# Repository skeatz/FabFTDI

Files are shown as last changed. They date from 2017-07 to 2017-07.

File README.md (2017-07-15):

# FabFTDI Projects
This repository contains all my FabFTDI projects:
FabFTDI projects which make use of avr microcontrollers are based on the V-USB library from [obdev](https://www.obdev.at/products/vusb/index.html) and the AVR-CDC work done by [K Ishikawa](http://www.recursion.jp/prose/avrcdc/) at recursion.jp.

A few points about the AVR-CDC protocol with Atmel microcontrollers - AVR-CDC enables a PC to communicate with a low-speed USB device (AVR microcontroller) through a virtual COM port.

The table below (from **recursion.jp**) lists the specifications for AVR-CDC with different AVR microcontrollers:
* AVR-CDC with USART (ATmega8/48/88/168/328)
    * speed: 600 - 38400 bps
    * datasize: 5 - 8 bits
    * parity: none/even/odd
    * stopbit: 1/2
    * controls: DTR, RTS, CTS
* AVR-CDC with USART (ATtiny2313)
    * speed: 600 - 38400 bps
    * datasize: 8
    * parity: none
    * stopbit: 1
* AVR-CDC without USART (ATtiny45/85)
    * speed: 1200 - 4800 bps
    * datasize: 8
    * stopbit: 1...

1. **[CH340G-based FabFTDI](fabftdi-ch340g.md)**
   * speeds up to 2 Mbps (loopback)
   * tested up to 250 kbps with ESP8266 module
   * uses hardware USB-to-TTL chip
   * low cost (USD0.40 per IC for 10 pcs)
2. **[ATmega8-based FabFTDI](fabftdi-mega8.md)**
   * speeds up to 2 Mbps (loopback)
   * tested up to 250 kbps with ESP8266 module
   * hardware UART
   * uses V-USB/AVR-CDC library
3. **[ATtiny2313-based FabFTDI](fabftdi-tiny2313.md)**
   * speed up to 57600 bps
   * hardware UART
   * uses V-USB library
4. **[ATtiny45-based FabFTDI (w/crystal)](fabftdi-tiny45x.md)**
   * speeds up to 4800 bps
   * uses V-USB library
5. **[ATtiny45-based FabFTDI (w/internal PLL)](fabftdi-tiny45.md)**
   * speeds up to 4800 bps
   * uses V-USB library

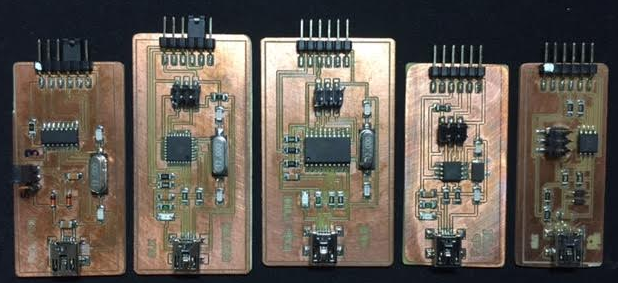
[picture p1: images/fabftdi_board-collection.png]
Fab FTDI collection


Collection of FabFTDI boards (from left): CH340g-based, ATmega8-based, ATtiny2313-based, ATtiny45-based w/crystal, ATtiny45-based w/internal oscillator

*Copyright (c) Steven Chew*...

*MIT license*

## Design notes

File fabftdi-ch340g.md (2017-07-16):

## Fab FTDI (CH340g)
* CH340g-based Fab FTDI
* tested up to:
  * 2 Mbps on loopback
  * 250000 bps with esp8266
* RTS/CTS flow control

## Schematic & Board Layout
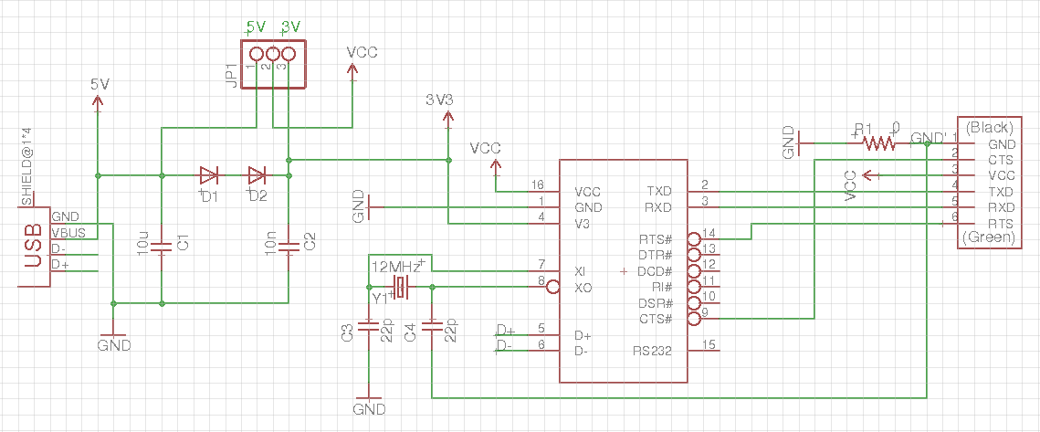
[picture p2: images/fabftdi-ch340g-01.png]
FabFTDI-CH340g Schematic


JP1 allows selection of 5V or 3.6V supply for FTDI interface

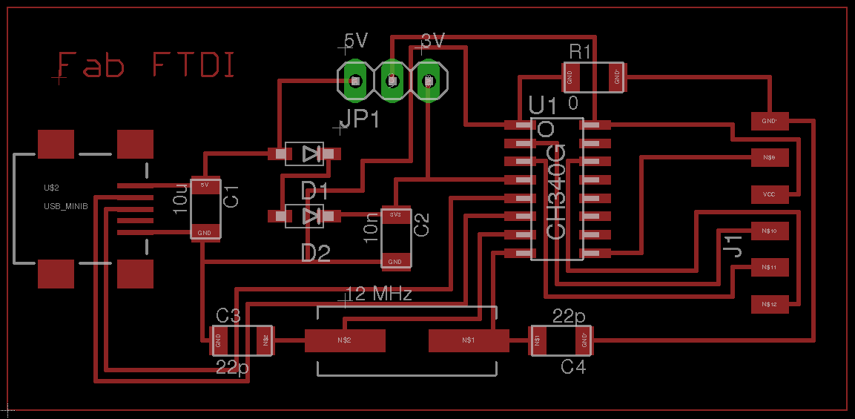
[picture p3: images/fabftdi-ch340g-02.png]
FabFTDI-CH340g layout


Mill and stuff the PCB.

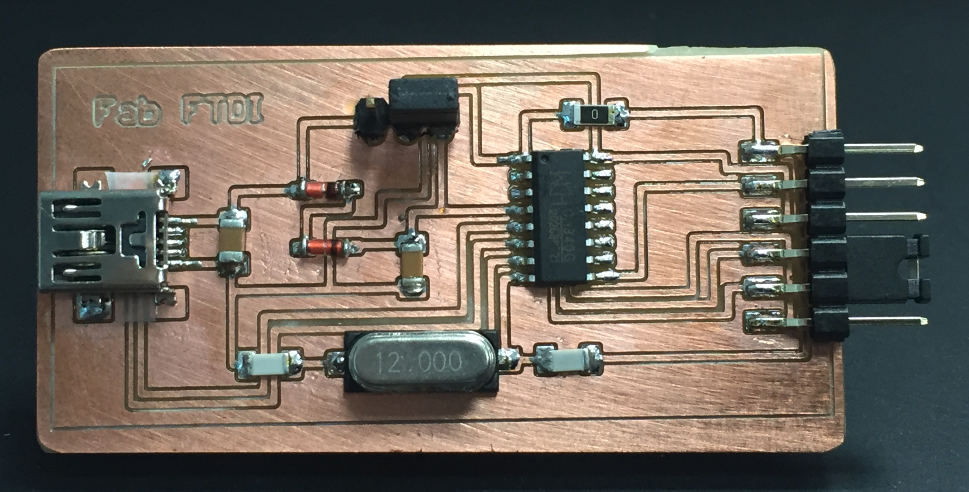
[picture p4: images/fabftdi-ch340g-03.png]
PCB after stuffing


Fab Modules downloads (1269dpi):

* [Fab modules - Board Outline](images/fabftdi-ch340g_outline.png)
* [Fab modules - Board traces](images/fabftdi-ch340g_traces.png)

## Component List
| Component | Component |
| :--- | :--- |
| 1 x CH340G | 1 x Mini-USB |
| 1 x 10uF  capacitor | 1 x PinHD 1x3|
| 1 x 10nF capacitor  | 1 x PinHD 1x6|
| 2 x 22pF capacitor  | 2 x Diodes 1N4148 |
| 1 x 12MHz crystal | 1 x 0 ohm R  |

## Testing the Board
Plug the FabFTDI-CH340g board into your computer's USB port. On a Windows machine, look for the COMport under Control Panel > System > Device Manager. You may need to install the CH340g driver. A signed driver can be downloaded here --> [CH340g driver](http://www.arduined.eu/files/CH341SER.zip). If you need help in installing the CH340g driver, you can refer to this [article](http://www.arduined.eu/ch340g-converter-windows-7-driver-download/).

Linux PCs and MacBooks should be able to detect the FabFTDI board without any driver. To check the device port:

`lsusb`

should display *QinHeng Electronics HL-340 USB-Serial adapter*

`ls /dev/ttyU*`

should display the device port.

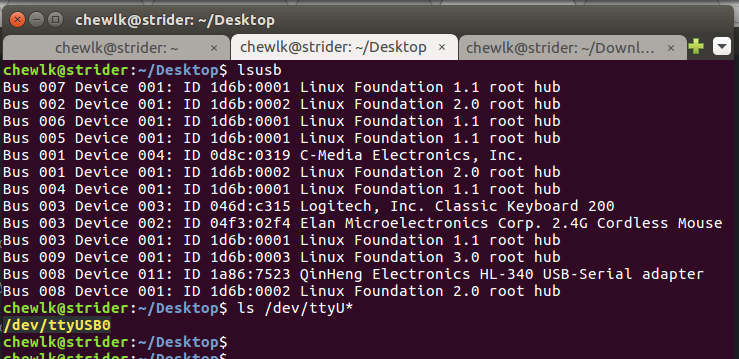
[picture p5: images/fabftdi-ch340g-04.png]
Detecting FabFTDI device port


To perform loopback test on the board, jumper the TXD and RXD pins. Open your favorite terminal emulation software, e.g. Arduino IDE or picocom. Select the device port.

E.g. for Arduino IDE on Linux, select Tools > Port > /dev/ttyUSB0. Click Serial Monitor (**Ctrl+Shift+M**). Select *Both NL & CR*. Select the desired baud rate. Type a message on the transmit window and press **Enter** or click the **Send** button. You should see the message appearing on the received data window.

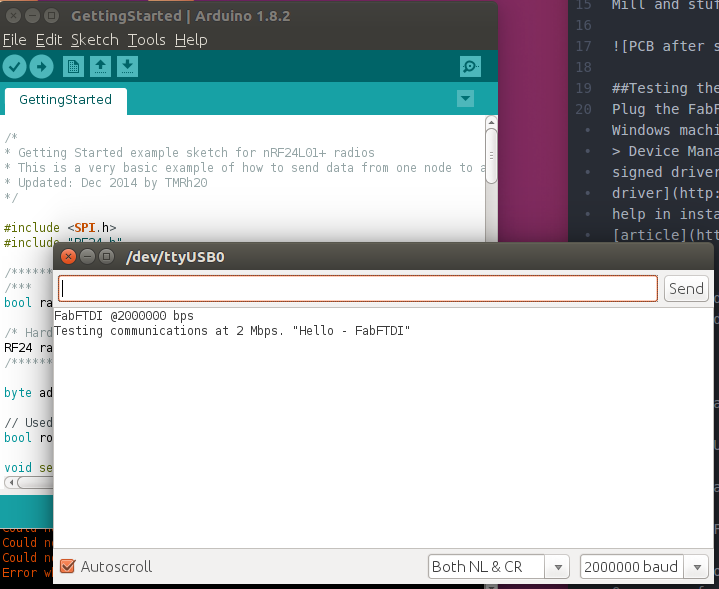
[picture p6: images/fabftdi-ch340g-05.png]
Loopback test


As stated at the start of this tutorial, I have tested the board up to 2 Mbps on loopback and 115200 bps on an ESP8266 module.

Good luck and have fun with your FabFTDI board!

## Files
* [Eagle Schematic](files/ch340g/fabftdi-ch340g.sch)

* [Eagle PCB layout](files/ch340g/fabftdi-ch340g.brd)

*Copyright (c) 2017-Steven Chew*

*MIT license*

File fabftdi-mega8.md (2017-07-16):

## FabFTDI - ATmega8
* ATmega8A-AU based Fab FTDI
* tested up to:
  * 2 Mbps on loopback
  * 250000 bps with ESP8266
* uses V-USB library
  * AVR-CDC from [Recursion.jp](http://www.recursion.jp/prose/avrcdc/)

## Schematic & Board Layout
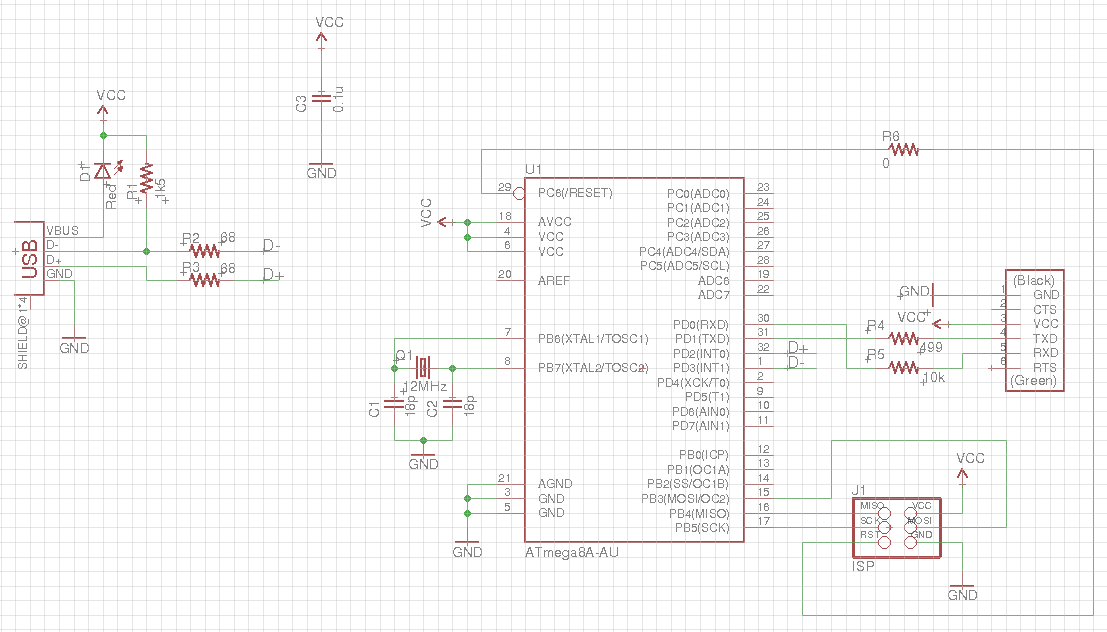
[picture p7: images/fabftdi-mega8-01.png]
FabFTDI-mega8 schematic


I opted to use a 12 MHz crystal in my design because I had some handy (bought for my CH340g-based FabFTDI). Also, ***the compiled .hex file is for an ATmega8 with 12 MHz crystal***. If you are using a different crystal oscillator, you will need to recompile from [source](http://www.recursion.jp/prose/avrcdc/download.html).

Only the TXD and RXD pins are implemented on the FTDI interface (no RTS/CTS).

The FTDI-Vcc is 3.6V. This means that it can work directly with 3.3V-based systems like the ESP8266. If you are interfacing with 5V boards, **do not connect the FTDI-Vcc to the target Vcc**, as I have not implemented 3.6V zeners for the USB D+ and D- lines.

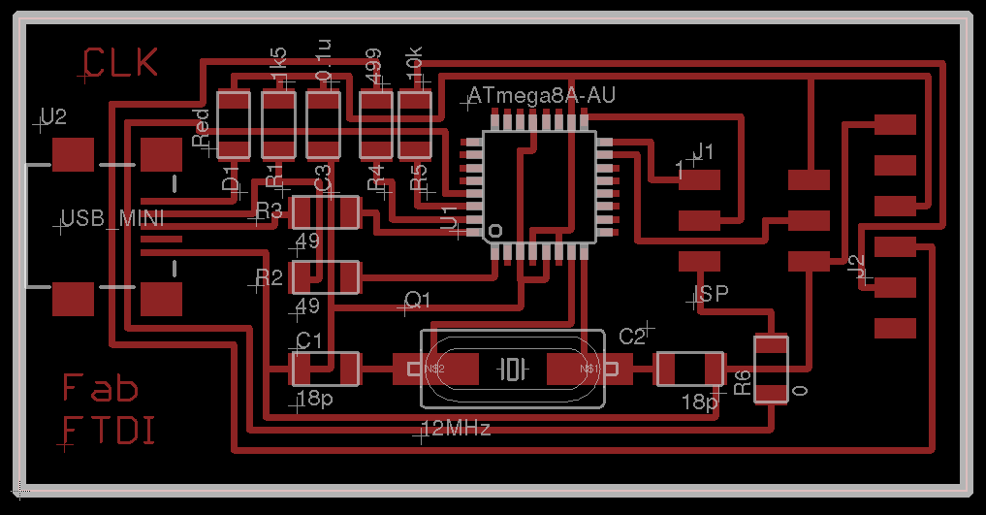
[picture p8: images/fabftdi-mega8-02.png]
FabFTDI-mega8 board layout


Fab modules downloads (1269dpi):
* [Fab modules - Board outline](images/fabftdi-mega8_outline.png)
* [Fab modules - Board traces](images/fabftdi-mega8_traces.png)

Mill and stuff the PCB.

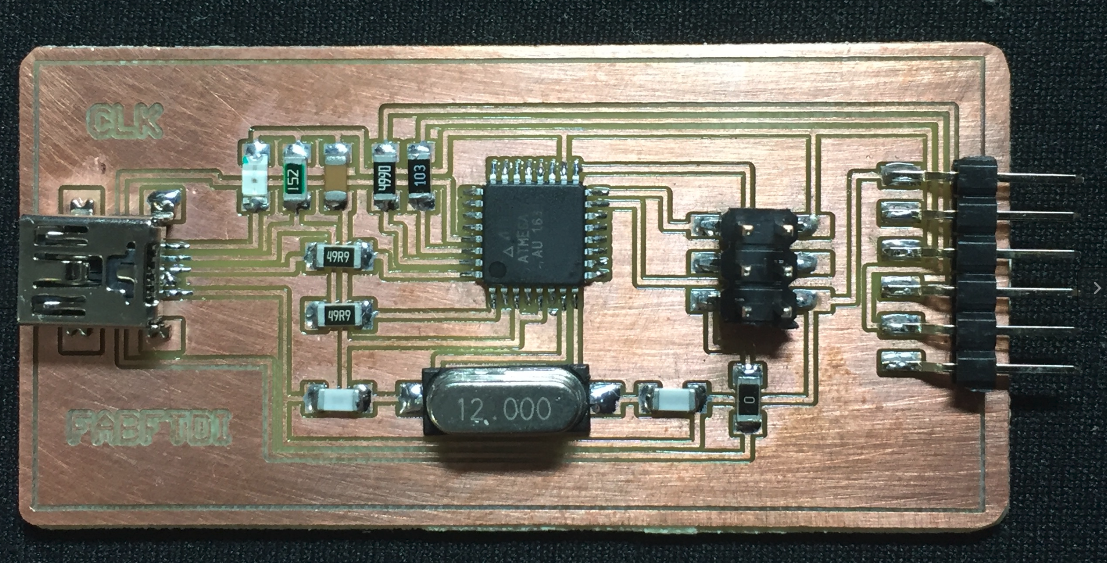
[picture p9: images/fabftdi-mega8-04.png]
FabFTDI board after stuffing


## Component List
| Components | Components |
| :--- | :--- |
| 1 x ATmega8A-AU | 1 x Mini-USB |
| 1 x 12 MHz Crystal | 1 x PinHD 2x3 ISP |
| 1 x LED red | 1 x PinHD 1x6 FTDI |
| 2 x 18pF capacitor | 1 x 0.1uF capacitor |
| 2 x 49 ohm R | 1 x 1k5 ohm R |
| 1 x 499 ohm R | 1 x 10k ohm R |
| 1 x 0 ohm R |

## Programming the Fab FTDI board
Unlike the CH340g-based FabFTDI, the ATmega8-based FabFTDI board uses the V-USB software library to implement USB-to-TTL conversion, i.e. it has to be programmed with the correct firmware before it can be used.

You need both an ISP programmer like the [FabISP](http://docs.academany.org/FabAcademy-Tutorials/_book/en/week4_electronic_production/fabisp.html) and [avrdude](http://savannah.nongnu.org/projects/avrdude) to program the FabFTDI-mega8 board. Instructions for installing avrdude can be found in the Fab Academy [tutorials](http://docs.academany.org/FabAcademy-Tutorials/_book/en/week4_electronic_production/fabisp.html) page. If you are using a different speed crystal oscillator, you will need to re-compile the firmware from [source](http://www.recursion.jp/prose/avrcdc/download.html).

Download the [FabFTDI-mega8 firmware](files/mega8/cdcmega8.hex).

Flash the firmware onto the FabFTDI-mega8 board using avrdude:

`avrdude -c usbtiny -p m8 -U flash:w:cdcmega8.hex -U lfuse:w:0xff:m -U hfuse:w:0x8f:m`

If you have managed to successfully flash the firmware onto the FabFTDI-mega8 board, give yourself a **pat** on the back. You are almost home.

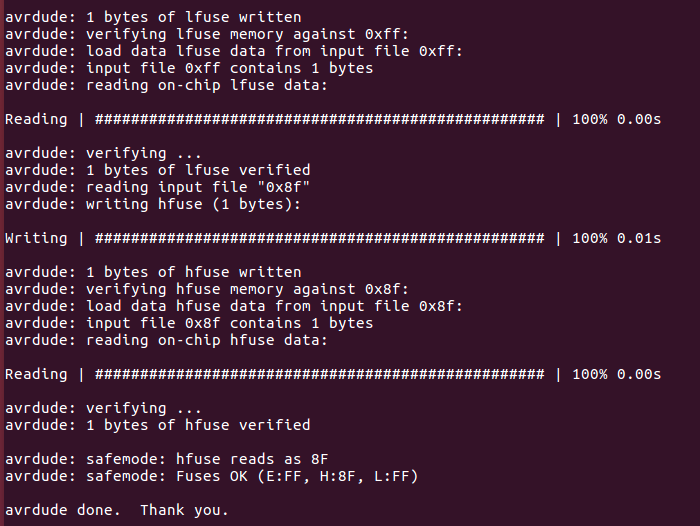
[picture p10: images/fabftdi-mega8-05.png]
Flashing the firmware


## Testing the Board
Plug the FabFTDI-mega8 board into your computer's USB port. Your computer should recognise the FabFTDI-mega8 board directly, as it implements the HIDinterface protocol.

On Windows machines, look for the COMport under Control Panel > System > Device Manager. On Linux or OSX machines, type the commands:
```
lsusb
ls /dev/ttyACM*
```
The FabFTDI-mega8 should appear as ***ID 16c0:05e1 Van Ooijen Technische Informatica Free shared USB VID/PID pair for CDC devices*** and ***/dev/ttyACM0***

To perform loopback test on the FabFTDI-mega8 board, jumper the TXD and RXD pins. Open your favorite terminal emulation software, e.g. Arduino IDE or picocom. Select the device port.

E.g. for Arduino IDE on Linux, select Tools > Port > /dev/ttyACM0. Click Serail Monitor (**Ctrl+Shift+M**). Select *Both NL & CR*. Select the desired baud rate. Type a message on the transmit window and press **Enter** or click the **Send** button. You should see the message appearing ont the received data window.

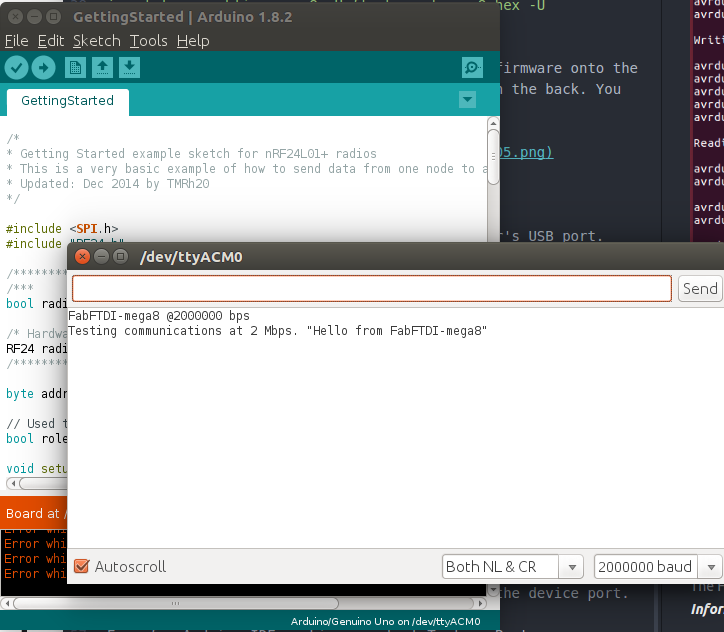
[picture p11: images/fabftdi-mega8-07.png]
Loopback test


As stated at the start of this tutorial, I have tested the FabFTDI-mega8 board up to 2 Mbps on loopback and 250 kbps on an ESP8266 module.

You can substitute the ATmega8A-AU with the ATmega328p-AU as the 2 devices are pin compatible.

Good luck and have fun with your FabFTDI board!

## Files
* [Eagle Schematic](files/mega8/fabftdi-mega8.sch)

* [Eagle PCB layout](files/mega8/fabftdi-mega8.brd)

* [FabFTDI-mega8 firmware (12MHz crystal)](files/mega8/cdcmega8.hex)

* [Firmware for ATmega328p (12MHz crystal)](files/mega8/cdcmega328p.hex)

*Copyright (c) 2017 Steven Chew*...

*MIT license*

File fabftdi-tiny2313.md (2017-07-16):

## FabFTDI - ATtiny2313
* ATtiny2313-based Fab FTDI
* hardware UART
* tested up to:
  * 57600 bps on loopback
* uses v-USB library
  * AVR-CDC from [Recursion.jp](http://www.recursion.jp/prose/avrcdc/)

## Schematic & Board Layout
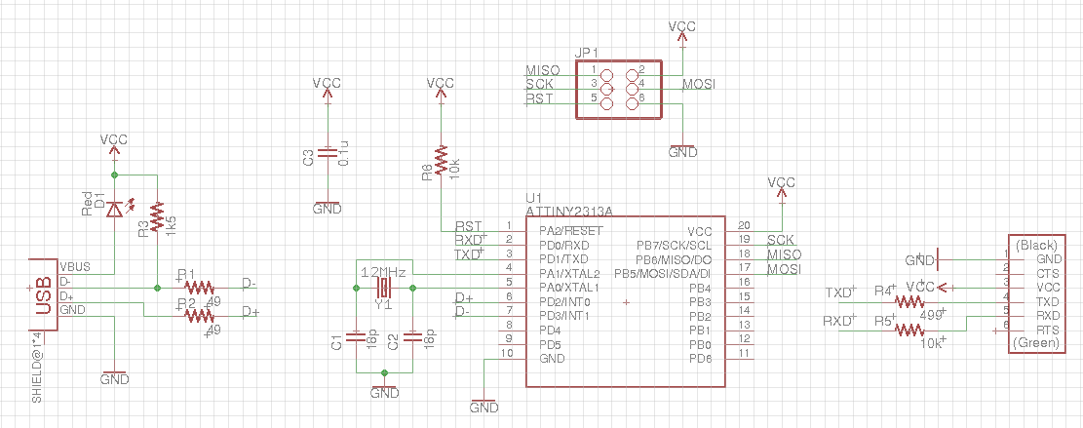
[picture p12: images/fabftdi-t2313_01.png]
Eagle schematic


I opted to use a 12 MHz crystal in my design because I had some handy (bought for my CH340g-based FabFTDI). Also, the ***compiled .hex file is for an ATtiny2313 with 12 MHz crystal.***. If you are using a different crystal oscillator, you will need to recompile the program from [source](http://www.recursion.jp/prose/avrcdc/download.html).

The FTDI Vcc is 3.6V, obtained by dropping the USB 5V through an LED. This means that it can work directly with 3.3V-based systems like the ESP8266 or ATxmega16E5. If you are interfacing with 5V boards, **do not connect the FTDI Vcc to the target Vcc**, as I have not implemented 3.6V zeners for the USB D+ and D= lines.

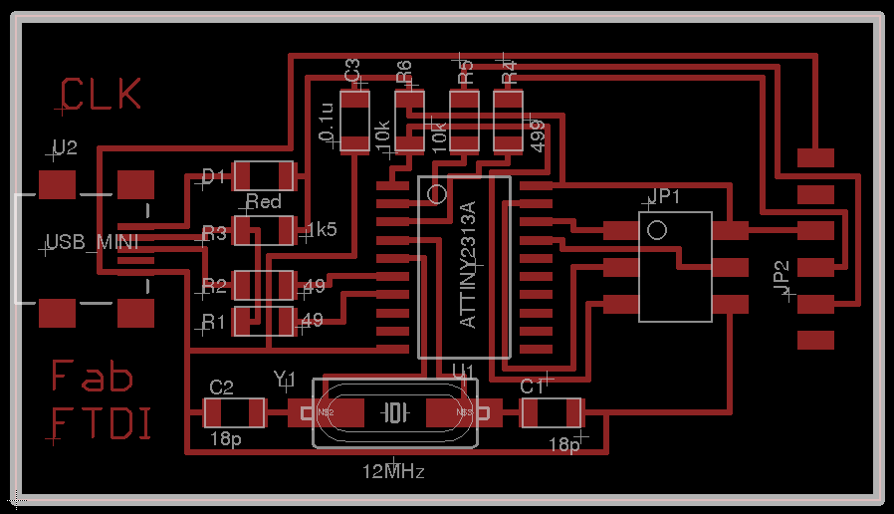
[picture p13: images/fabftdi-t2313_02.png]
Eagle PCB layout


*FabFTDI-t2313 pcb layout*

Fab modules downloads (1269dpi):

* [Fab modules - board outline](images/fabftdi-t2313_outline.png)
* [Fab modules - board traces](images/fabftdi-t2313_traces.png)

Mill and stuff the PCB

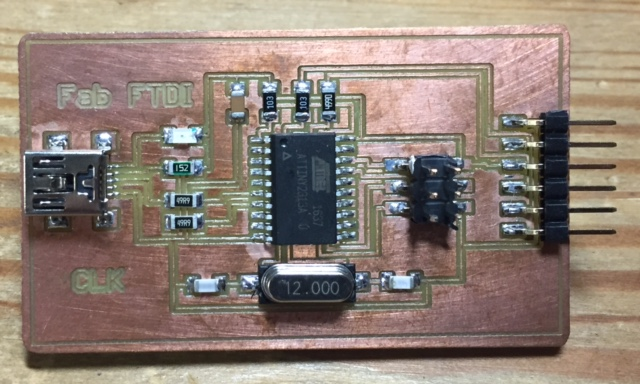
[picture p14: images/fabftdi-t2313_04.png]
FabFTDI board after stuffing


## Component List
| Component | Component |
| :--- | :--- |
| 1 x ATtiny2313 | 1 x Mini-USB |
| 1 x 12 MHz crystal | 1 x PinHD 2x3 ISP |
| 1 x LED red | 1 x PinHD 1x6 FTDI |
| 2 x 18pF capacitor | 1 x 0.1uF capacitor |
| 2 x 10k ohm R | 1 x 1k5 ohm R |
| 1 x 499 ohm R | 2 x 49 ohm R |

## Programming the Fab FTDI board
Unlike the CH340g-based FabFTDI, the ATmega8-based FabFTDI board uses the V-USB software library to implement USB-to-TTL conversion, i.e. it has to be programmed with the correct firmware before it can be used.

You need both an ISP programmer like the [FabISP](http://docs.academany.org/FabAcademy-Tutorials/_book/en/week4_electronic_production/fabisp.html) and [avrdude](http://savannah.nongnu.org/projects/avrdude) to program the FabFTDI-mega8 board. Instructions for installing avrdude can be found in the Fab Academy [tutorials](http://docs.academany.org/FabAcademy-Tutorials/_book/en/week4_electronic_production/fabisp.html) page. If you are using a different speed crystal oscillator, you will need to re-compile the firmware from [source](http://www.recursion.jp/prose/avrcdc/download.html).

Download the [FabFTDI-t2313 firmware](files/tiny2313/cdc2313.hex).

Flash the firmware onto the FabFTDI-t2313 board using avrdude:

`avrdude -c usbtiny -p t2313 -U flash:w:cdc2313.hex -U lfuse:w:0xff:m -U hfuse:w:0xcd:m`

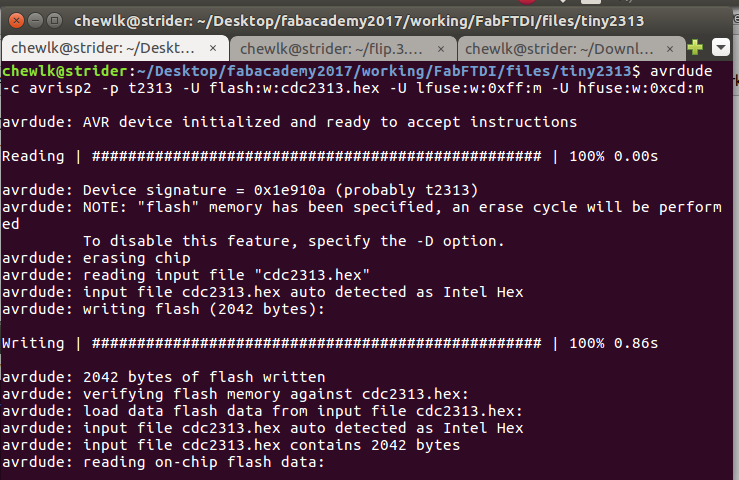
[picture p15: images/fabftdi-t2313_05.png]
Flashing the firmware


If you have managed to successfully flash the firmware onto the FabFTDI-t2313 board, give yourself a **pat** on the back. You are almost home.

## Testing the Board
Plug the FabFTDI-t2313 board into your computer's USB port. Your computer should recognise the FabFTDI-t2313 board directly, as it implements the HIDinterface protocol.

On Windows machines, look for the COMport under Control Panel > System > Device Manager. On Linux or OSX machines, type the commands:
```
lsusb
ls /dev/ttyACM*
```
The FabFTDI-t2313 should appear as ***ID 16c0:05e1 Van Ooijen Technische Informatica Free shared USB VID/PID pair for CDC devices*** and ***/dev/ttyACM0***

To perform loopback test on the FabFTDI-mega8 board, jumper the TXD and RXD pins. Open your favorite terminal emulation software, e.g. Arduino IDE or picocom. Select the device port.

E.g. for Arduino IDE on Linux, select Tools > Port > /dev/ttyACM0. Click Serail Monitor (**Ctrl+Shift+M**). Select *Both NL & CR*. Select the desired baud rate. Type a message on the transmit window and press **Enter** or click the **Send** button. You should see the message appearing ont the received data window.

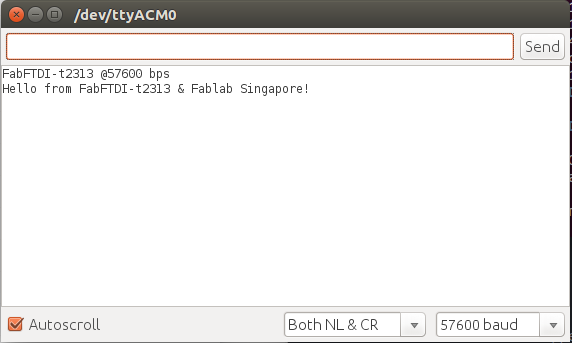
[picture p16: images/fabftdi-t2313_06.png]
Loopback test


As stated at the start of this tutorial, I have tested the FabFTDI-t2313 board up to 57600 bps on loopback only.

Good luck and have fun with your FabFTDI board!

## Files
* [Eagle Schematic](files/tiny2313/fabftdi-tiny2313.sch)

* [Eagle PCB layout](files/tiny2313/fabftdi-tiny2313.brd)

* [FabFTDI-t2313 firmware (12MHz crystal)](files/tiny2313/cdc2313.hex)

* [FabFTDI-t2313 firmware (16MHz crystal)](files/tiny2313/cdc2313-16.hex)

* [FabFTDI-t2313 firmware (20MHz crystal)](files/tiny2313/cdc2313-20.hex)

*Copyright (c) 2017 Steven Chew*...

*MIT license*

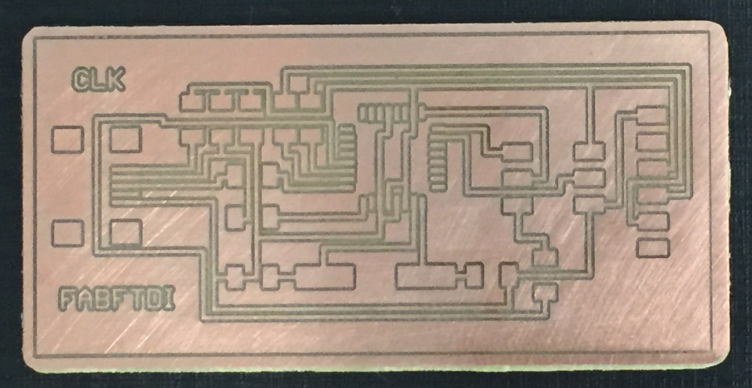
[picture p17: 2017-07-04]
images/fabftdi-mega8-03.png

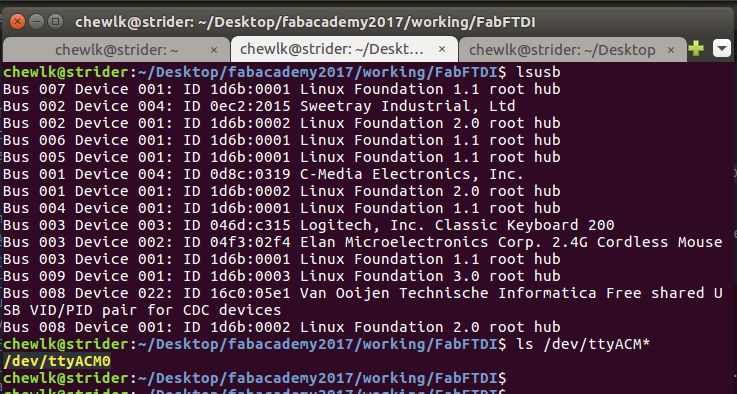
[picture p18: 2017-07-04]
images/fabftdi-mega8-06.png

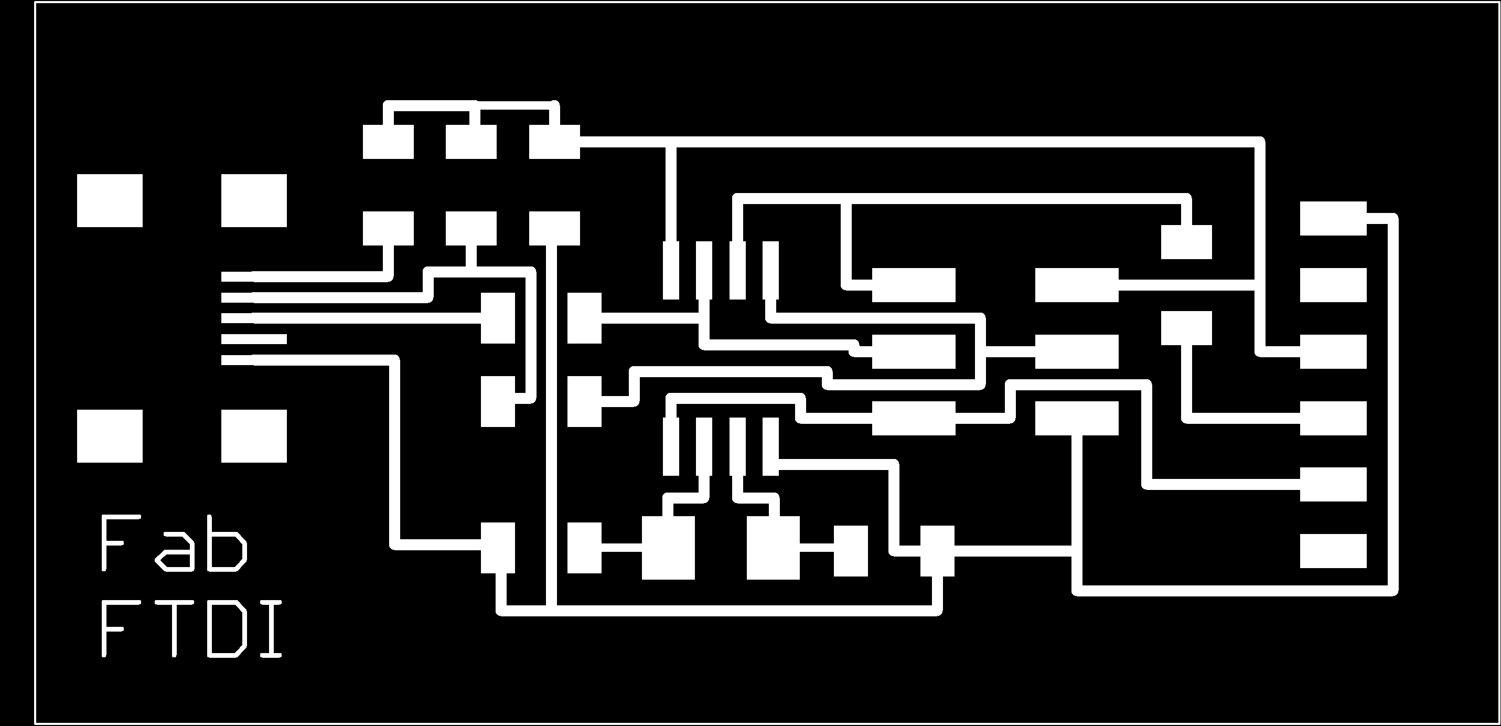
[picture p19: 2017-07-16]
images/fabftdi-t45x_02.png

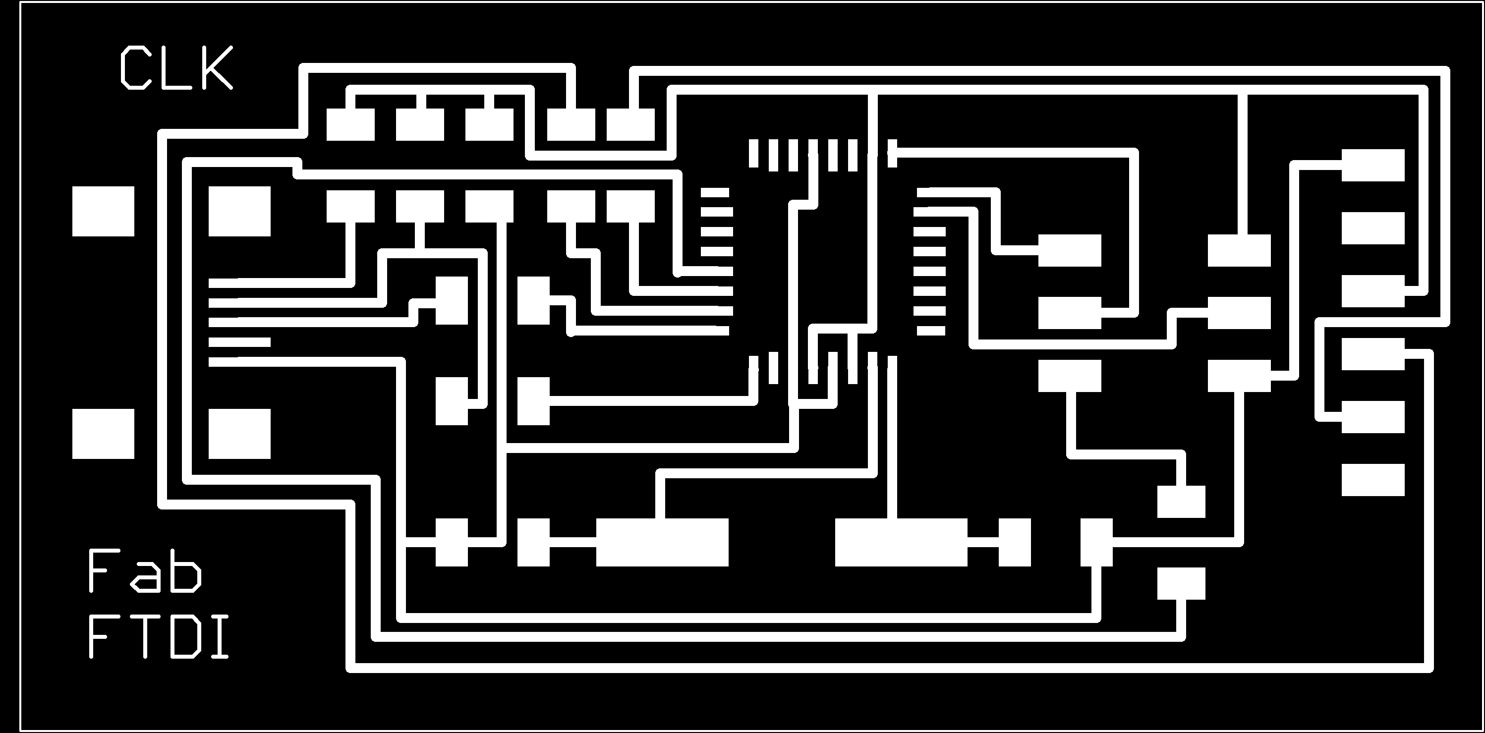
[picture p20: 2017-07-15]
images/fabftdi-mega8_traces.png

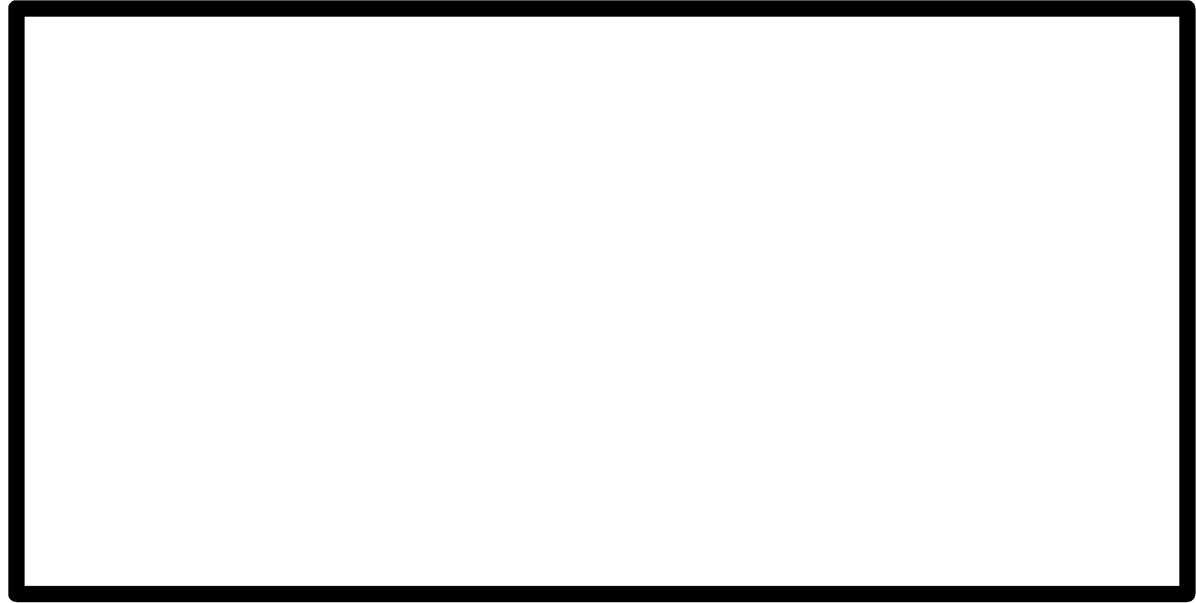
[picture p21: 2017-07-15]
images/fabftdi-mega8_outline.png

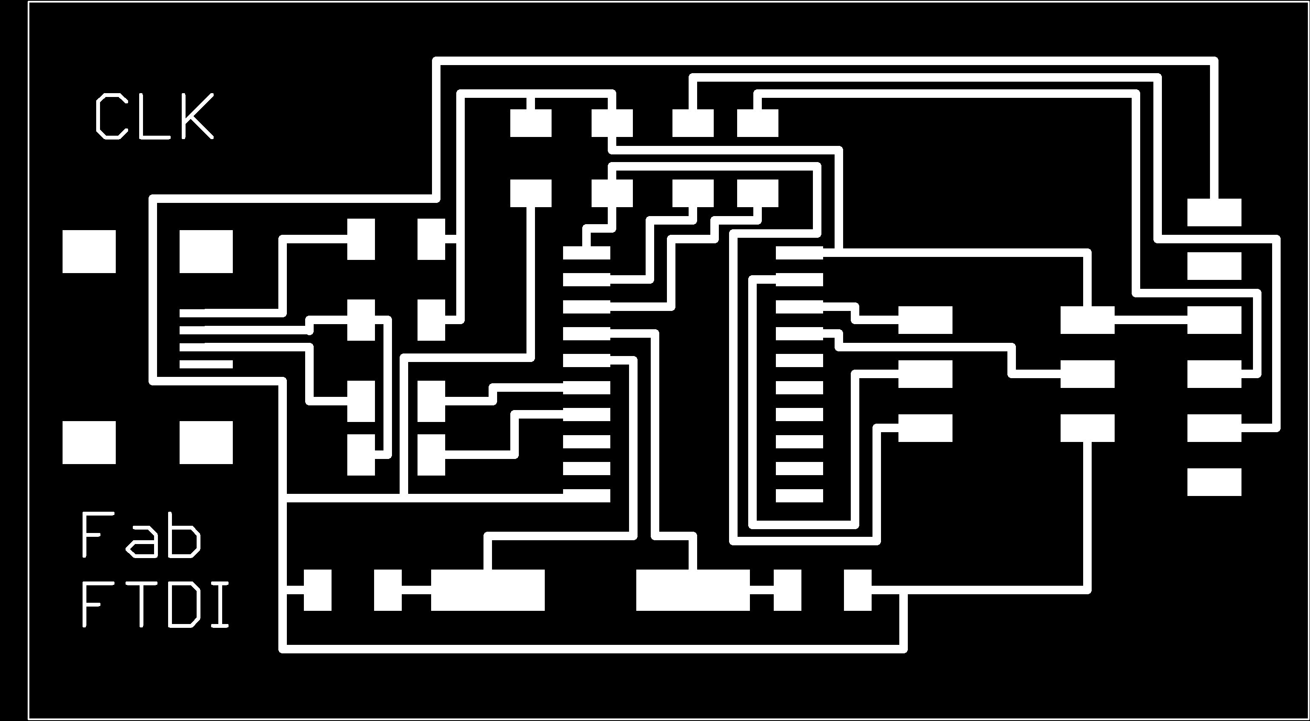
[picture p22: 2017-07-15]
images/fabftdi-t2313_traces.png

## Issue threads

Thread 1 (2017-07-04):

add fab-production files

Madouc, 2017-07-04:
Cool! thanks for these.
to increase adaptation i would add board, outline and component png´s that are ready for production to the repository.

skeatz, 2017-07-05:
Yup; will do so later. I've been working on these for the past couple of weeks, when I could spare the time. Only just started writing up the tutorials. Will improve upon it as I go along.

skeatz, 2017-07-05:
Hi Bas,

Noted. Will update documents to include these later. Was working on these boards during the past 2 weeks, when I had the time. Decided to do a quick write-up & post to GitHub late last night, so kind of a rush job.

cheers,

Steven

________________________________
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

skeatz, 2017-07-15:
Added traces & outline pngs for fab modules. Board layout & finished board already included.

Closed 2017-07-15.

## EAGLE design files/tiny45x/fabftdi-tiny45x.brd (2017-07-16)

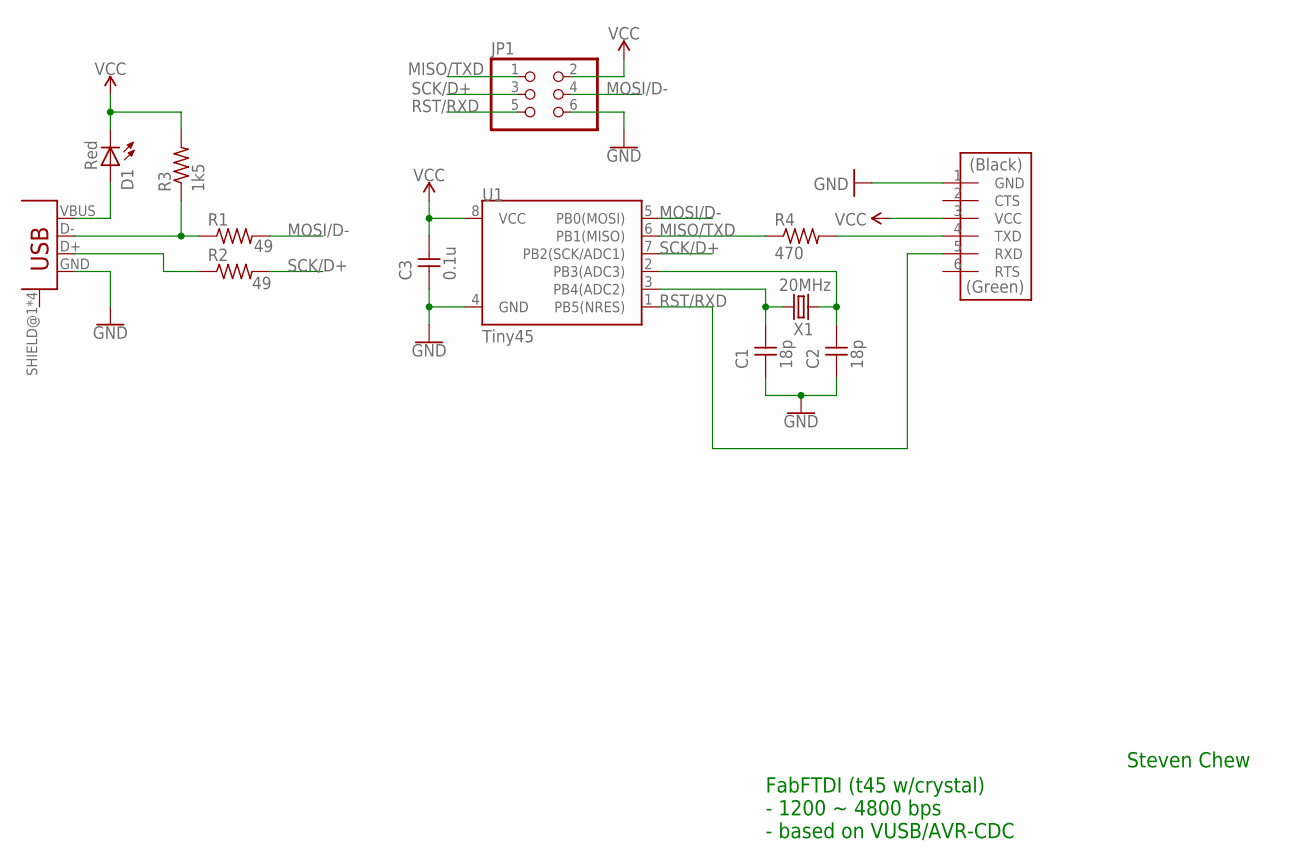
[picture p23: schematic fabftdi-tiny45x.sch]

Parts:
C1, C2: 18p; C1206FAB
C3: 0.1u; C1206FAB
D1: Red; LED1206FAB
JP1: PINHD-2X3-SMDFAB; 2X03SMD-FAB
JP2: FTDI-SMD-HEADER; 1X06SMD
R1, R2: 49; R1206FAB
R3: 1k5; R1206FAB
R4: 470; R1206FAB
U1: Tiny45; SO08-EIAJ
U2: USB_MINI
X1: 20MHz; 2-SMD-5X3MM

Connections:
GND: C1.1, C2.1, C3.1, JP1.6, JP2.1 (GND), U1.4 (GND), U2.GND
MISO/TXD: JP1.1, R4.1, U1.6 (PB1(MISO))
MOSI/D-: JP1.4, R1.2, U1.5 (PB0(MOSI))
unnamed: R1.1, R3.1, U2.D-
unnamed: R2.1, U2.D+
unnamed: D1.1 (A), U2.VBUS
unnamed: C1.2, U1.3 (PB4(ADC2)), X1.P$2 (2)
unnamed: C2.2, U1.2 (PB3(ADC3)), X1.P$1 (1)
unnamed: JP2.4 (TXD), R4.2
RST/RXD: JP1.5, JP2.5 (RXD), U1.1 (PB5(NRES))
SCK/D+: JP1.3, R2.2, U1.7 (PB2(SCK/ADC1))
VCC: C3.2, D1.2 (C), JP1.2, JP2.3 (VCC), R3.2, U1.8 (VCC)

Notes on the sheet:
Steven Chew
FabFTDI (t45 w/crystal) - 1200 ~ 4800 bps - based on VUSB/AVR-CDC

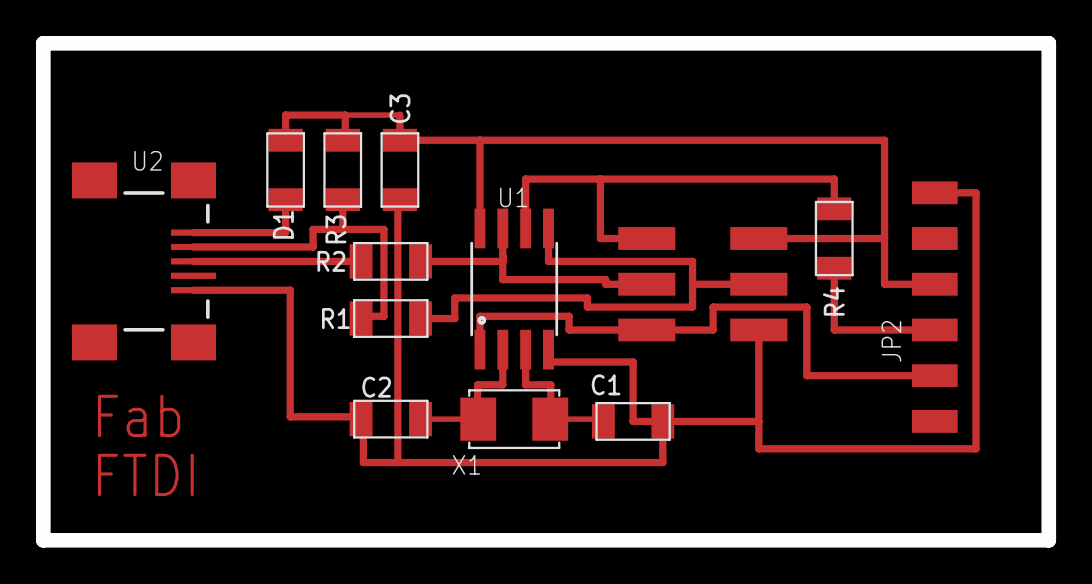
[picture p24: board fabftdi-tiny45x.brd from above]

Board: 2 copper layers, 55.9 x 27.6 mm, 13 parts (0 on the bottom side), 12 nets.

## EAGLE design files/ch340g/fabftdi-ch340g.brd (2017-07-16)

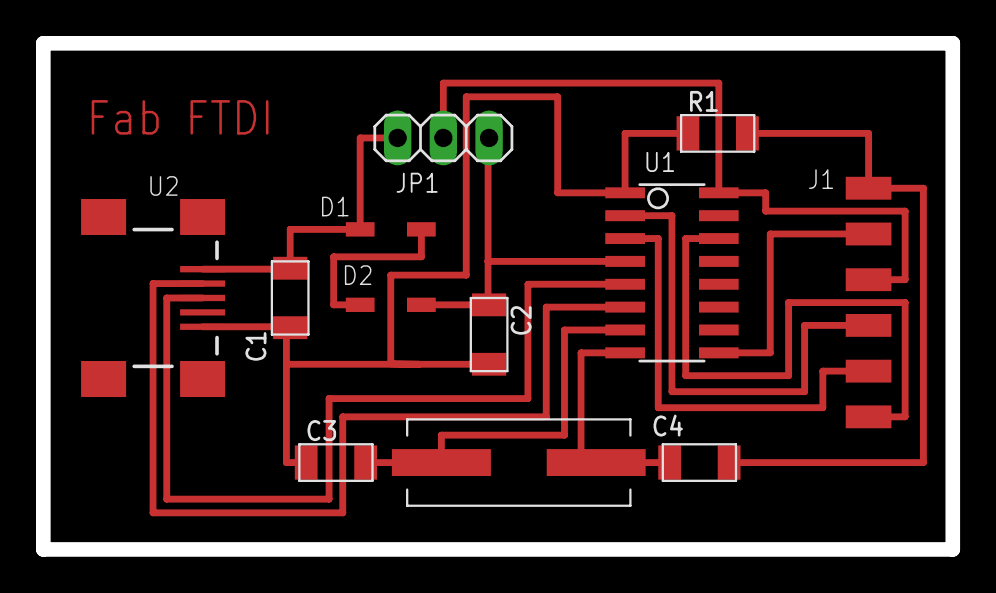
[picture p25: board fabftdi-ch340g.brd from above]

Board: 2 copper layers, 50.5 x 28.1 mm, 12 parts (0 on the bottom side), 14 nets.

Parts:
C1: 10u; C1206FAB
C2: 10n; C1206FAB
C3, C4: 22p; C1206FAB
D1, D2: SOD123
J1: FTDI; 1X06SMD
JP1: 1X03
R1: 0; R1206FAB
U1: CH340G; SOIC16
U2: USB_MINIB
Y1: 12MHz; CRYSTAL-SMD-10.5X4.8-2PIN

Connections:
3V3: C2.1, D2.CATHODE, JP1.3, U1.4
5V: C1.1, D1.ANODE, JP1.1, U2.VBUS
D+: U1.5, U2.D+
D-: U1.6, U2.D-
GND: C1.2, C2.2, C3.1, R1.1, U1.1, U2.GND
GND': C4.1, J1.1, R1.2
unnamed: C4.2, U1.8, Y1.P$1
unnamed: C3.2, U1.7, Y1.P$2
unnamed: D1.CATHODE, D2.ANODE
unnamed: J1.2, U1.9
unnamed: J1.4, U1.2
unnamed: J1.5, U1.3
unnamed: J1.6, U1.14
VCC: J1.3, JP1.2, U1.16

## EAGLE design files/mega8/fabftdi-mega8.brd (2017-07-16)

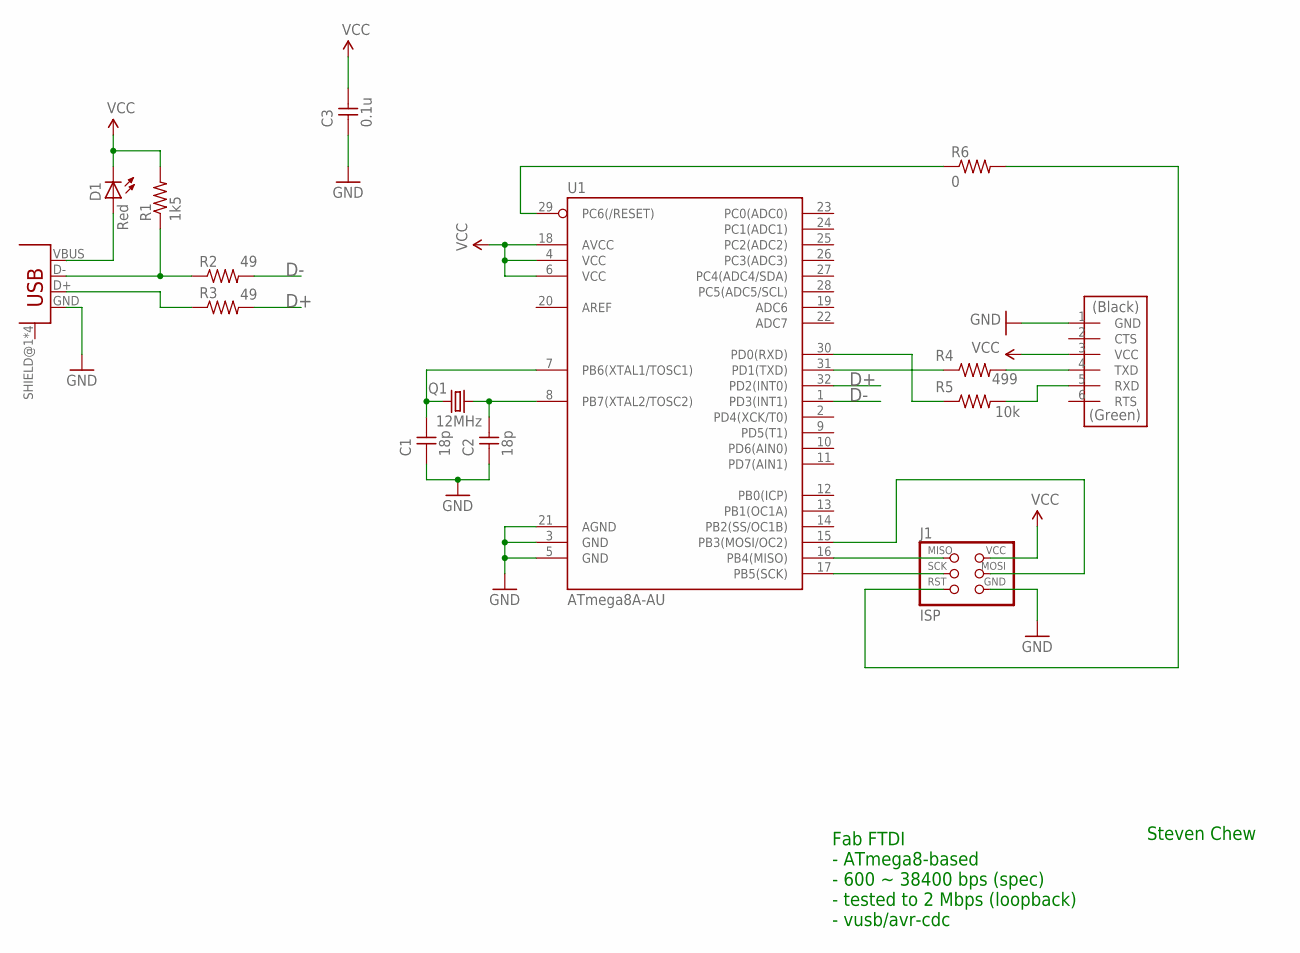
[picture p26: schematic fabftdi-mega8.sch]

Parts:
C1, C2: 18p; C1206FAB
C3: 0.1u; C1206FAB
D1: Red; LED1206FAB
J1: ISP; 2X03SMD
J2: FTDI-SMD-HEADER; 1X06SMD
Q1: 12MHz; HC49UP
R1: 1k5; R1206FAB
R2, R3: 49; R1206FAB
R4: 499; R1206FAB
R5: 10k; R1206FAB
R6: 0; R1206FAB
U1: ATmega8A-AU; TQFP32-08THIN
U2: USB_MINI

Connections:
D+: R3.2, U1.32 (PD2(INT0))
D-: R2.2, U1.1 (PD3(INT1))
GND: C1.1, C2.1, C3.1, J1.6 (GND), J2.1 (GND), U1.3 (GND), U1.5 (GND), U1.21 (AGND), U2.GND
unnamed: C2.2, Q1.2, U1.8 (PB7(XTAL2/TOSC2))
unnamed: C1.2, Q1.1, U1.7 (PB6(XTAL1/TOSC1))
unnamed: R4.1, U1.31 (PD1(TXD))
unnamed: R5.1, U1.30 (PD0(RXD))
unnamed: J1.1 (MISO), U1.16 (PB4(MISO))
unnamed: D1.1 (A), U2.VBUS
unnamed: R1.1, R2.1, U2.D-
unnamed: R3.1, U2.D+
unnamed: J1.3 (SCK), U1.17 (PB5(SCK))
unnamed: J1.4 (MOSI), U1.15 (PB3(MOSI/OC2))
unnamed: J2.4 (TXD), R4.2
unnamed: J1.5 (RST), R6.2
unnamed: R6.1, U1.29 (PC6(/RESET))
unnamed: J2.5 (RXD), R5.2
VCC: C3.2, D1.2 (C), J1.2 (VCC), J2.3 (VCC), R1.2, U1.4 (VCC), U1.6 (VCC), U1.18 (AVCC)

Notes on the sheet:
Steven Chew
Fab FTDI - ATmega8-based - 600 ~ 38400 bps (spec) - tested to 2 Mbps (loopback) - vusb/avr-cdc

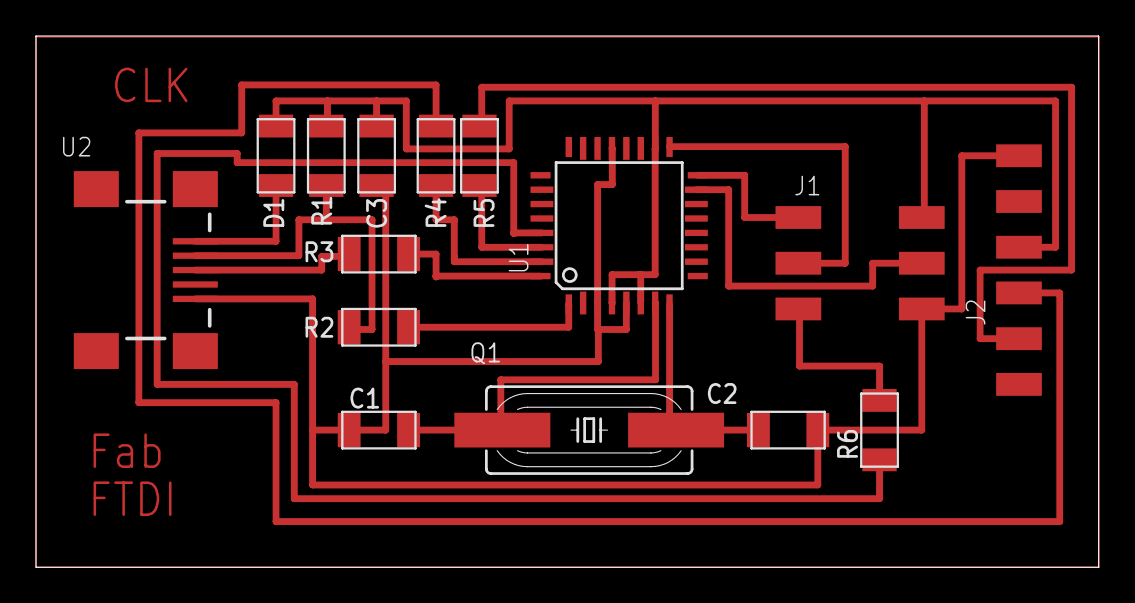
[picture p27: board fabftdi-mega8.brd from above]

Board: 2 copper layers, 59.0 x 29.5 mm, 15 parts (0 on the bottom side), 18 nets.

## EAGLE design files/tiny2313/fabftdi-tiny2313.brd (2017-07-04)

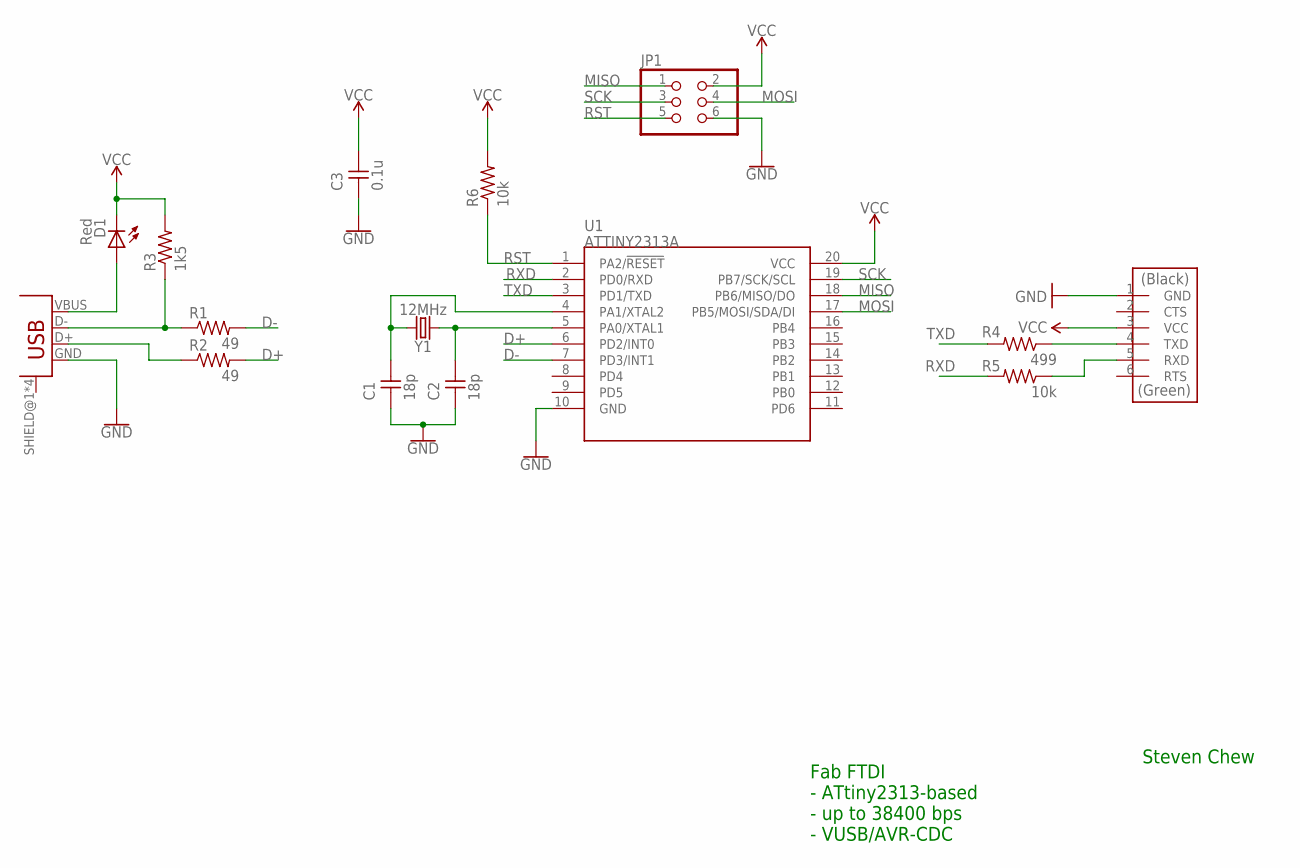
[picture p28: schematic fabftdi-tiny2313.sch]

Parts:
C1, C2: 18p; C1206FAB
C3: 0.1u; C1206FAB
D1: Red; LED1206FAB
JP1: PINHD-2X3-SMDFAB; 2X03SMD-FAB
JP2: FTDI-SMD-HEADER; 1X06SMD
R1, R2: 49; R1206FAB
R3: 1k5; R1206FAB
R4: 499; R1206FAB
R5, R6: 10k; R1206FAB
U1: ATTINY2313A; SOP20W
U2: USB_MINI
Y1: 12MHz; HC49UP

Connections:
D+: R2.2, U1.6 (PD2/INT0)
D-: R1.2, U1.7 (PD3/INT1)
GND: C1.1, C2.1, C3.1, JP1.6, JP2.1 (GND), U1.10 (GND), U2.GND
MISO: JP1.1, U1.18 (PB6/MISO/DO)
MOSI: JP1.4, U1.17 (PB5/MOSI/SDA/DI)
unnamed: D1.1 (A), U2.VBUS
unnamed: C2.2, U1.5 (PA0/XTAL1), Y1.1
unnamed: C1.2, U1.4 (PA1/XTAL2), Y1.2
unnamed: JP2.4 (TXD), R4.1
unnamed: JP2.5 (RXD), R5.1
unnamed: R1.1, R3.1, U2.D-
unnamed: R2.1, U2.D+
RST: JP1.5, R6.1, U1.1 (PA2/!RESET)
RXD: R5.2, U1.2 (PD0/RXD)
SCK: JP1.3, U1.19 (PB7/SCK/SCL)
TXD: R4.2, U1.3 (PD1/TXD)
VCC: C3.2, D1.2 (C), JP1.2, JP2.3 (VCC), R3.2, R6.2, U1.20 (VCC)

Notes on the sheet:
Steven Chew
Fab FTDI - ATtiny2313-based - up to 38400 bps - VUSB/AVR-CDC

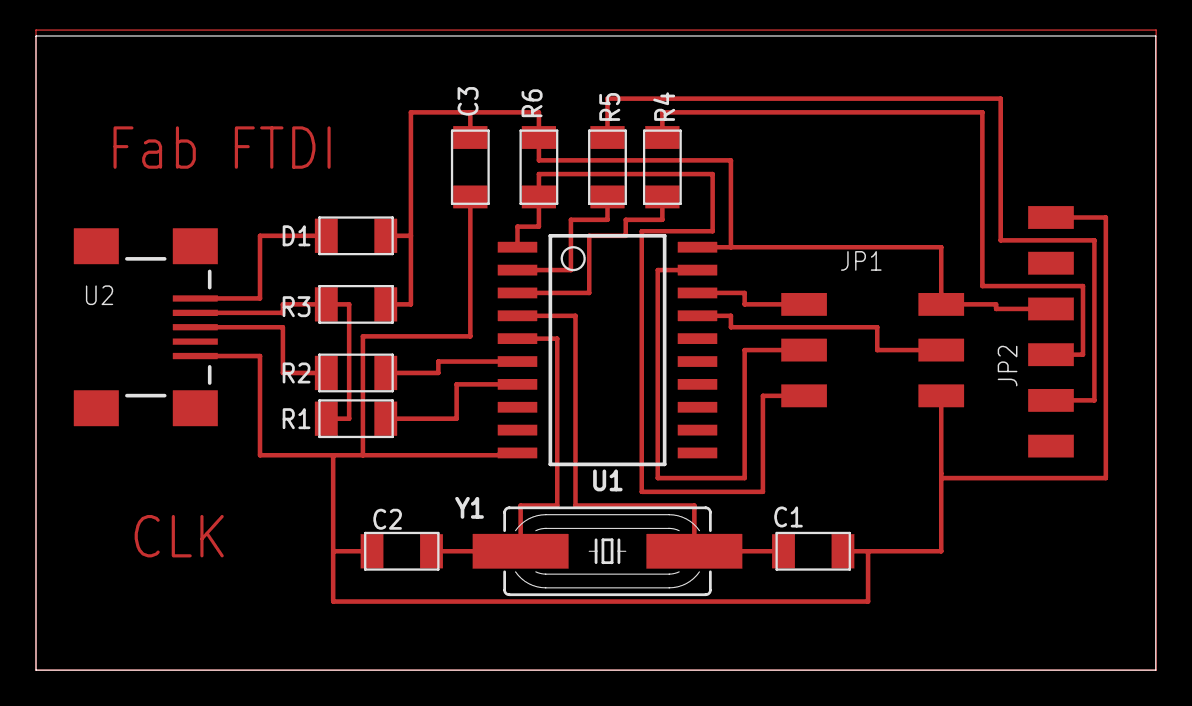
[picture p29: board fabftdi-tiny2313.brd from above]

Board: 2 copper layers, 62.2 x 35.2 mm, 15 parts (0 on the bottom side), 17 nets.

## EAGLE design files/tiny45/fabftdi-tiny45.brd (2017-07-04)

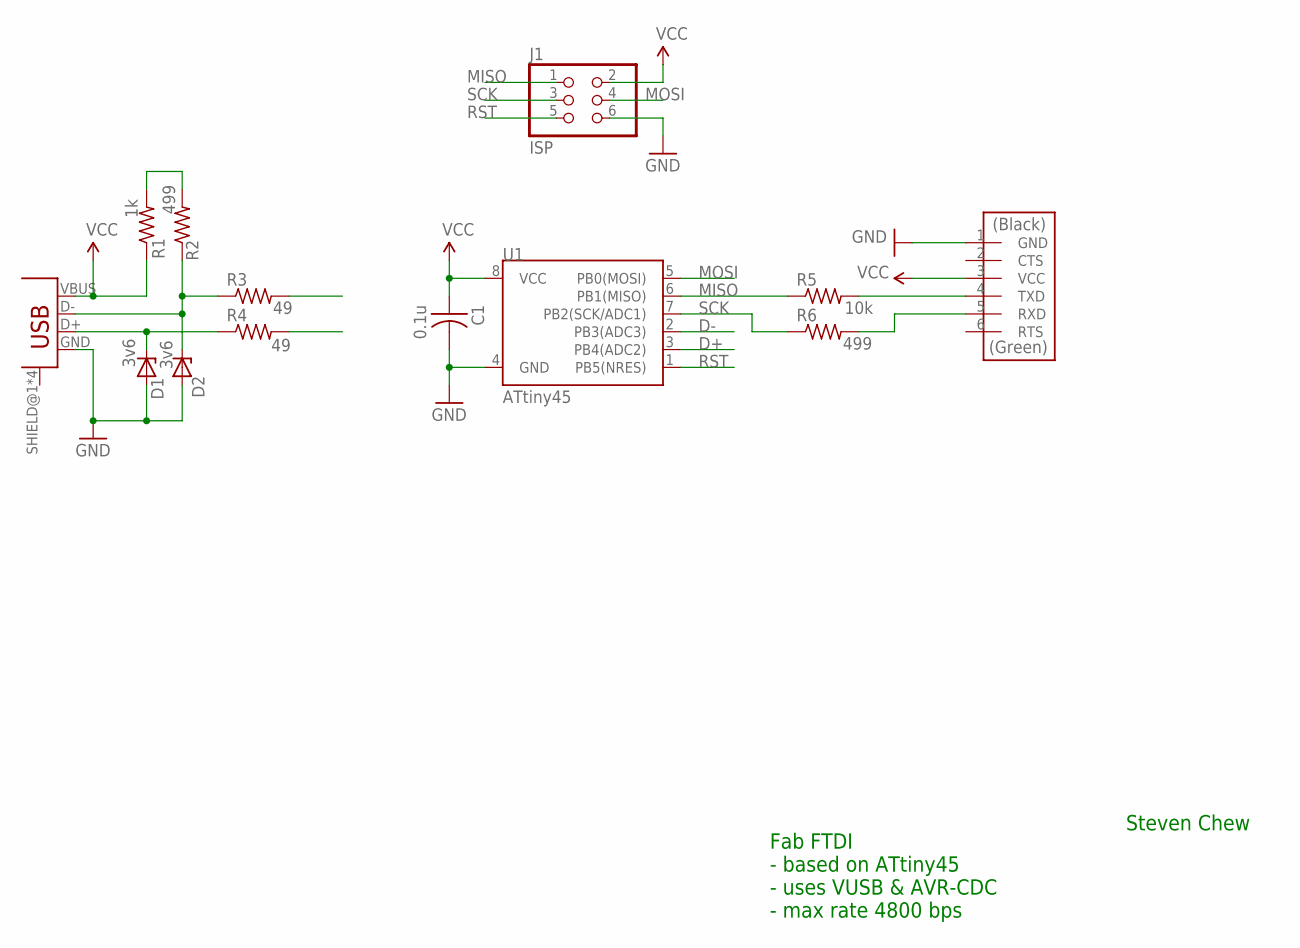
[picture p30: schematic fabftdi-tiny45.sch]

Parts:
C1: 0.1u; C1206FAB
D1, D2: 3v6; SOD123
J1: ISP; 2X03SMD-FAB
J2: FTDI-SMD-HEADER; 1X06SMD
R1: 1k; R1206FAB
R2, R6: 499; R1206FAB
R3, R4: 49; R1206FAB
R5: 10k; R1206FAB
U1: ATtiny45; SO08-EIAJ
U2: USB_MINI

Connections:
D+: R4.2, U1.3 (PB4(ADC2))
D-: R3.2, U1.2 (PB3(ADC3))
GND: C1.2, D1.ANODE, D2.ANODE, J1.6, J2.1 (GND), U1.4 (GND), U2.GND
MISO: J1.1, R5.1, U1.6 (PB1(MISO))
MOSI: J1.4, U1.5 (PB0(MOSI))
unnamed: D1.CATHODE, R4.1, U2.D+
unnamed: D2.CATHODE, R2.1, R3.1, U2.D-
unnamed: R1.2, R2.2
unnamed: J2.4 (TXD), R5.2
unnamed: J2.5 (RXD), R6.2
RST: J1.5, U1.1 (PB5(NRES))
SCK: J1.3, R6.1, U1.7 (PB2(SCK/ADC1))
VCC: C1.1, J1.2, J2.3 (VCC), R1.1, U1.8 (VCC), U2.VBUS

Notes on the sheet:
Steven Chew
Fab FTDI - based on ATtiny45 - uses VUSB & AVR-CDC - max rate 4800 bps

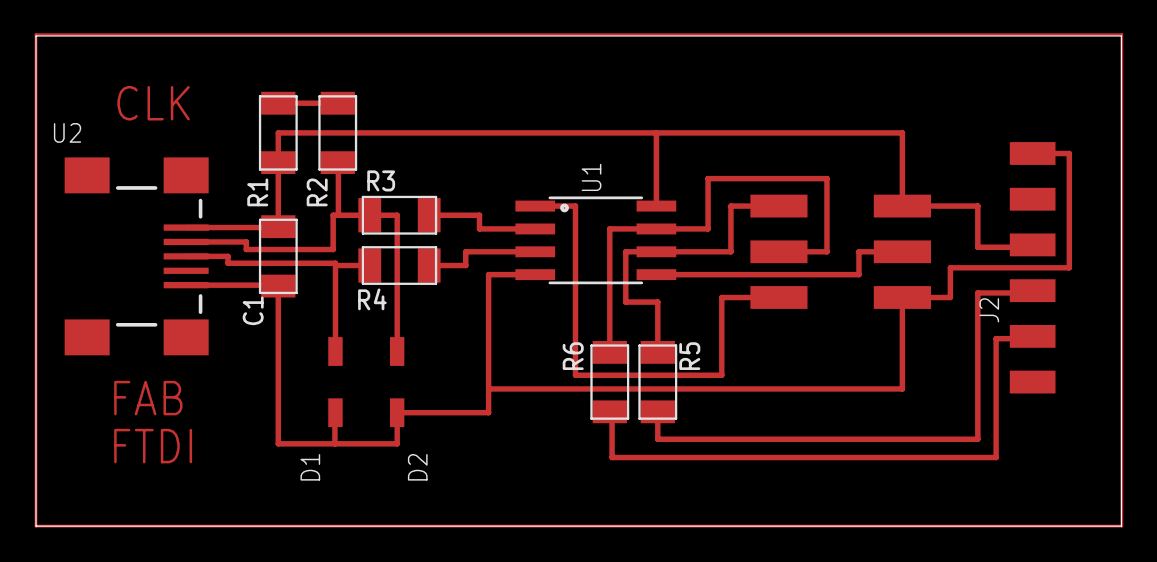
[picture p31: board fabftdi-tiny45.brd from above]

Board: 2 copper layers, 60.3 x 27.2 mm, 13 parts (0 on the bottom side), 13 nets.

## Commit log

2017-07-04 Added CH340g FTDI
    [fabftdi-ch340g.brd, fabftdi-ch340g.sch]
2017-07-04 fixed ch340g files link
    [fabftdi-ch340g.brd, fabftdi-ch340g.sch]
2017-07-04 added design files for other FabFTDI
    [fabftdi-mega8.brd, fabftdi-mega8.sch, fabftdi-tiny2313.brd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]
2017-07-15 Added fabmodules board outline & traces
2017-07-15 updated mega8 eagle files
    [fabftdi-mega8_v1.1.brd, fabftdi-mega8_v1.1.sch]
2017-07-15 added board collection
2017-07-16 updated all files, added components list
    [fabftdi-ch340g.brd, fabftdi-ch340g.sch, fabftdi-mega8.brd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]

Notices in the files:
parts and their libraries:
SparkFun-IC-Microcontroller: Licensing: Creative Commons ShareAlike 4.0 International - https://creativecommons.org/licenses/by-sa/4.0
